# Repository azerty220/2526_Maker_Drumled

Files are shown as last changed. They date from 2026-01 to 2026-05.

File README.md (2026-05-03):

# 2526_Maker_Drumled

## Elise Firmin

### Description :
 
Le projet consiste à mettre des leds sur la caisse-claire d’une batterie. Ces led s’allumeraient lorsque la caisse-claire reçoit un coup. De plus, il y aurait un encodeur permettant de choisir la couleur de l’éclairage.
Le projet a pour but d’être amovible ; c’est-à-dire qu’il puisse être ajouté puis retiré de la caisse claire. 
Une partie conception 3D est envisagée afin de mettre le projet sur le contour de la caisse claire sans gêner les frappes du batteur, et qu’il n’y ait pas besoin de démonter les peaux pour insérer les leds. Ainsi, nous évitons de faire des trous dans une caisse claire afin de relier l’encodeur.

### Quelques images d'une caisse claire et de ce que l'on trouve actuellement sur le marché :

#### Exemple de caisse claire :
Nous pouvons voir le fût sur lequel l'on pourra fixer le système et le déclencheur que l'on ne doit pas gêner en revanche. 

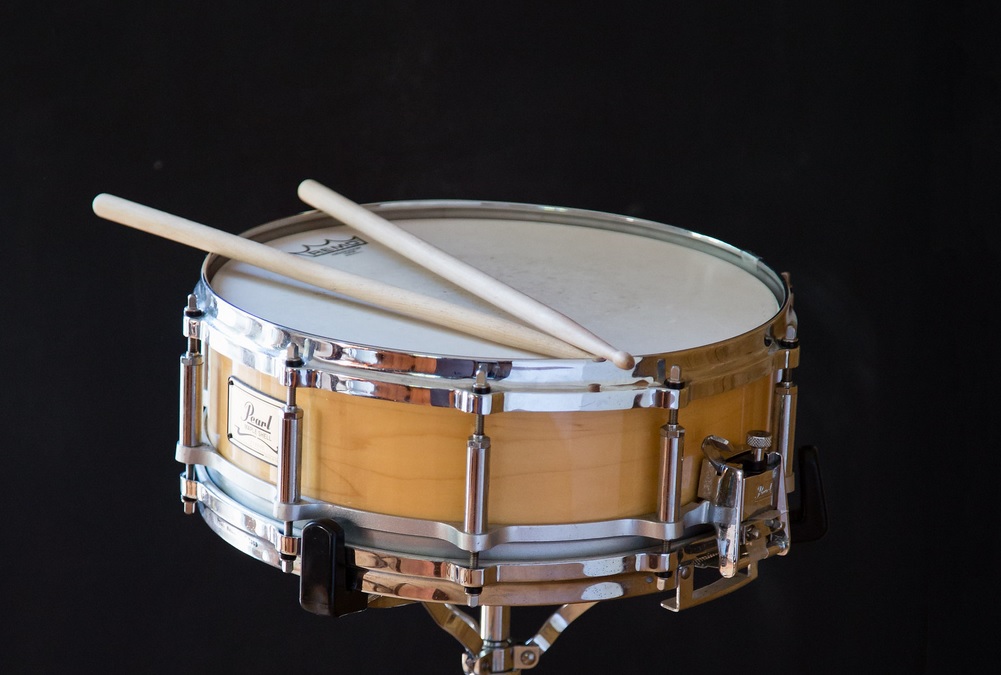
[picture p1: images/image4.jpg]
caisse claire


#### Système d'éclairage existant :

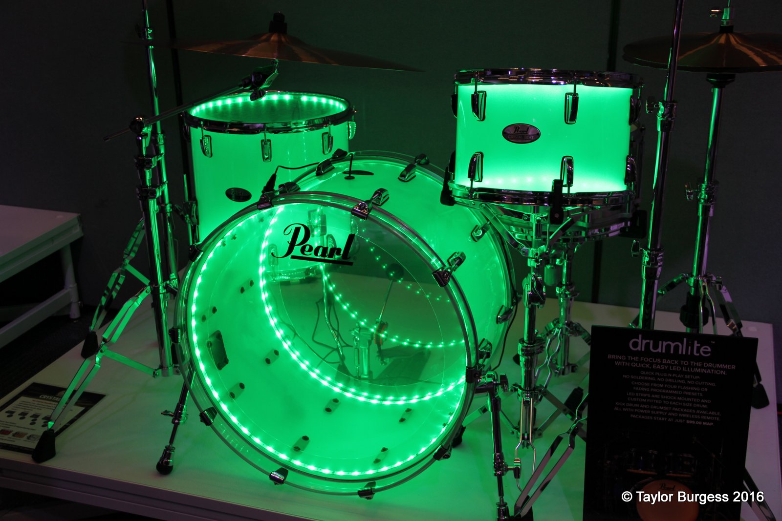
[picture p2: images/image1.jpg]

#####
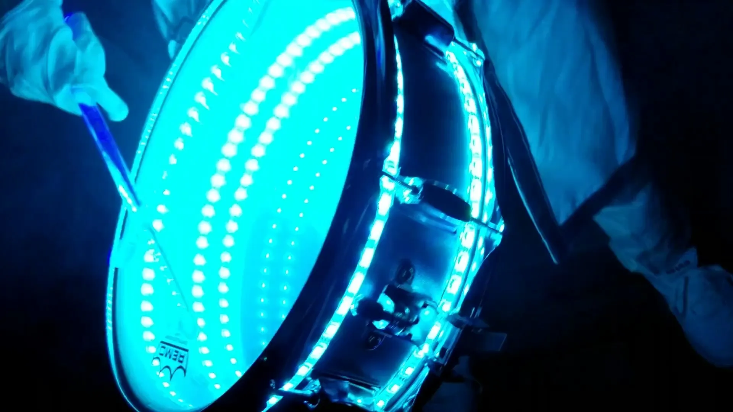
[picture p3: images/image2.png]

#####
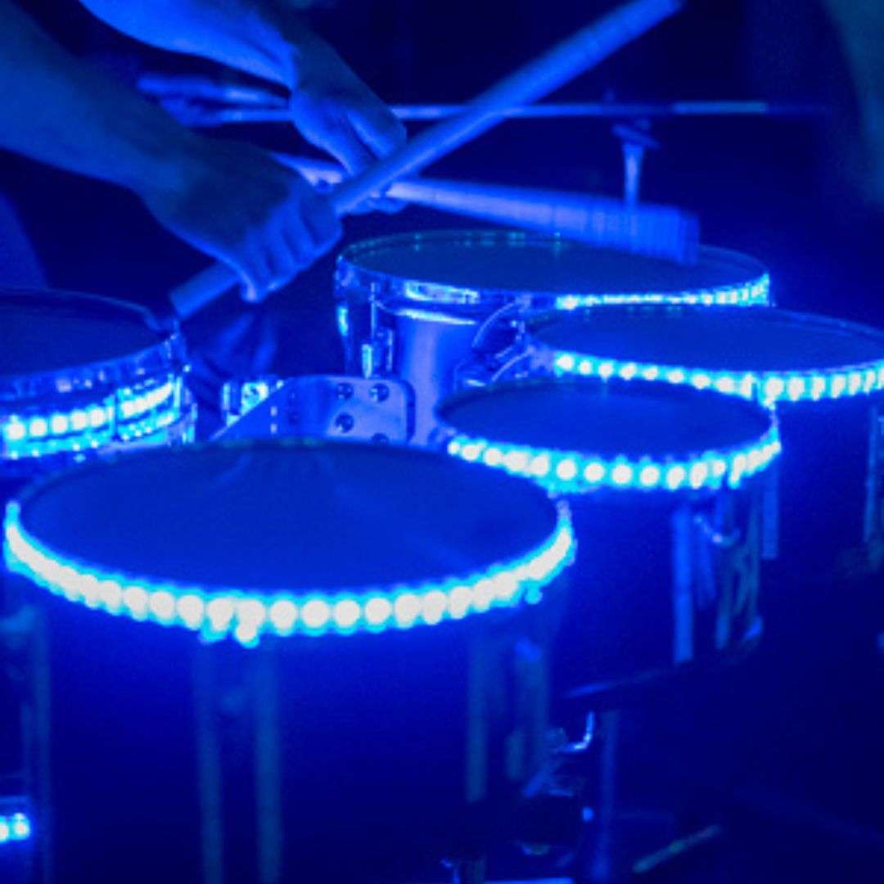
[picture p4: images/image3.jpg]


### Rétroplanning du projet :

Se référer à la partie "Projects" avec le nom "Retroplanning".

retroplanning

## Mécanique :

Il a fallu faire attention que le timbre puisse s'enclencher et se déclencher sans problème. Aussi, ne pas supperposer la partie mécanique aux pièces mécaniques de la caisse-claire elle-même. L'imprimante 3D a été choisie de façon à qu'elle ait un plateau suffisamment grand pour imprimer cette pièce mécanique. 

La partie mécanique se fait en 3 parties :

- 2 parties pour l'anneau autour de la caisse claire, qui s'aimante afin que le tout tienne autour de la caisse-claire. Les aimants sont choisis assez puissants (12kg minimum conseillé), et le tout est assez solide pour ne pas glisser vers le bas. L'une des moitiés d'anneau est adaptée pour recevoir le pcb qui se fixe à l'aide de vis et d'un fer à souder chaud. 

- Le support de la batterie, qui possède 4 trous afin de pouvoir le fixer à l'anneau autour de la caisse claire, à l'aide de vis et d'un fer à soudé chaud.

## Le code :

Le seuil du capteur est à régler dans le code du projet. Le code est séparé en plusieurs parties avec notamment les fonctions importantes qui sont exécutées dans la boucle du main. Un fichier concerne l'acquisition du capteur, un autre les données envoyées à la bande neopixel selon la couleur dirigée par le bouton hardware, et l'acquisition du capteur. 

## La batterie :

Malheureusement, la batterie construite ne permet pas de gérer les appels de courants du circuit, en revanche, en branche une alimentation électrique, le projet est fonctionnel. Il faut changer le composant qui permet de rguler les batteries qui sont en série pour en prendre un plus performant, ou bien utiliser une batterie qui possède une seule cellule est une autre soluton. 

## Le hardware

Plusieurs connectiques de composants ont été adaptées pour avoir des connectiques plus petites et réduire la taille du pcb. Notamment la connectique du ruban de led neopixels pour la convertir en un connecteur jmc de petite taille. 

De plus, lors des tests du projet, le maintien du bouton reset était nécessaire pour la compilatiion du code ; ainsi, la résistance R3 du pcb est inutile : elle s'enlève très facilement du pcb à l'aide d'un coupe-ongle par exemple. Ou bien, sans fer à souder, la température d'un briquet étant de 800°C à 1000°C, cela peut être tenté ; mais attention au risque de brûlure. 

La petite taille du pcb permet un poids léger. 

Le PCB a été conçu à l'aide du logiciel KiCad.

## Piste d'amélioration du projet :

Le projet pourrait être amélioré grâce à des effets codés comme un chazer par exmple, puis un bouton hardware associé. 
De plus, il pourrait être pertinent de mettre un bouton qui permettrait en appuyant 4 fois dessus par l'utilisateur de déterminer un BPM et que les led ne s'allument plus à chaque coup cette fois ci, mais à chaque temps, ce qui constiturait une aide pour le batteur pour conserver le tempo.
En mêlant cette dernière idée avec le projet initial, et étendu à la batterie tout entière, cela donnerait l'accès à des personnes mal entendante à cet instrument, que ce soit une sourdité partiel ou complète.

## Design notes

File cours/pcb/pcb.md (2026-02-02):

UART : communication du Tx vers le Rx. Ligne de 0 et de 1 avec des bits de start, stop. Il faut une masse commune aussi.

I2C : une ligne SDA et SCL pour tous les esclaves. Avec une resistance qui relie les lignes à la masse, dont la valeur est variable selon les cas.

100kHz (standard) : 4.7kohm, 10kohm

400kHz (fast) : 2.2kohm, 4.7kohm

etc

SPI : SCLK, MOSI, MISO, CS (1 par esclave) [CS, CS2, CS3,...]. Plus rapide que l'I2C mais ça nécessite plus de connexion.

USB : pour remplacer l'UART, uniformiser, mais l'UART existe encore parce qu'il est plus facile à mettre en place.

Mettre des résistances de 5k1ohm entre CC1 et la masse et CC2 et la masse.

On met un composant qui a 5 diodes (pour enlever des pics de tension qui surviendrait, s'assurer que la tension soit comprise entre 0 et 5V) : à mettre au plus proche du port usb.

Rajoute du fil sur les pistes les plus courtes pour qu'elles soient de même longueur que les autres pistes.

Mettre une résistance en série (1kohm) puis un condensateur en parallèle vers la masse (0.01microF) et une résistance en parallèle vers du 5V (100k) pour un switch pour éviter les rebonds.

Diode TVS, pour enlever tout ce qui est au dessus d'un certain seuil pour ne pas griller le pcb. A installer au plus proche du connecteur. à chaque connecteur où il y a du signal (connecteur de batterie ce n'est pas intéressant) 

Vdd : transistor haut
Vss : transistor bas

Lorsqu'on crée une empreinte :

alim en haut

masse en bas

Dans le symbol editor 

Symbol Editor > New librairy 

Project > OK, save

SMD ou Through hole (THT) (traversant)

PowerFlag pour corriger, signaler qu'on sait qu'il faut une alim par exemple

Input : Reçoit un signal provenant d’une autre source

Output : Génère un signal destiné à être utilisé par un autre composant. 2 output ne peuvent pas être câblés ensemble

Bidirectionnel : Peut fonctionner à la fois en entrée et en sortie (ex : SDA en I2C)

Power Input : Pin recevant une alimentation (ex : VCC, GND)

Power Output : Pin délivrant une alimentation (ex : sortie d’un régulateur de
tension)

Tri-State : Sortie pouvant être active, inactive ou en haute impédance

Open Collector/Open Drain : Sortie nécessitant une résistance de pull-up pour
fonctionner correctement

Passive : Utilisé pour des connexions simples comme des résistances ou
condensateurs

Unspecified : Type de pin non défini (par défaut dans certains cas)

Point ou triangle sur la pin 1

Faire attention au fait que les dimensions soient en mm, en cm, en pouces,...

F.Cu : Couche de cuivre côté supérieur (composants côté top)

B.Cu : Couche de cuivre côté inférieur (composants côté bottom)

F.Paste : Zone pour la crème à braser sur le top (pour les composants CMS)

B.Paste : Zone pour la crème à braser sur le bottom (pour les composants CMS)

F.Silkscreen : Sérigraphie sur la face supérieure (références, symboles, repères)

B.Silkscreen : Sérigraphie sur la face inférieure

F.Mask : Masque de soudure (protège les pistes, expose les pads pour la soudure)

B.Mask : Masque de soudure sur la face inférieure

F.Courtyard : Délimitation physique de l’empreinte du composant pour éviter les
chevauchements

B.Courtyard : Même chose mais côté Bottom

F.Fab : Informations précises sur la fabrication du PCB, notamment les
dimensions exactes du composant

B.Fab : Même chose mais côté bottom.

F : Front et B : Back

Lorsqu'on est dans une page, et qu'on crée un label hiérarchique (avec petit losance, ou demi carré,... : entrée/sortie d'une "fonction"), il n'apparaît pas automatiquement dans la vue d'ensemble, il faut faire clic droit dans la vue d'ensemble sur la page 

Remplir le MPN (ou MFR) dans tous les composants un peu spécifiques (pas les résistances et condensateurs standards)

Checker le ERC (Electrical Rules Checker) : il ne doit y avoir aucune erreur 

Commencer par définir la taille du pcb, et les trous de fixation

Mettre le microcontrolleur avec beaucoup de pin au milieu

Mettre les connecteurs sur les côtés

Possibilité de switcher deux pins sur la schématique sur un microcontrolleur pour éventuellement faciliter le routage par exemple. 

4 couches : plan de masse et plan d'alimentation

1 via = 1 ampère

JLCPCB : là où on fait fabriquer nos pcb

Pour choisir le nombre de couche et la disposition : deuxième icone à côté de l'icone enregistrer > Physical Stackup (Ne pas changer In1, In2, In3,... pour la fabrication mais la partie "VCC",... on peut)

Option sur jlcpcb : 

1oz = 35 microns

On garde les options de base (1oz ligne 1, 0.5oz ligne 2)

Dimensions inférieuresà100mmx100mm,

4 couches maximum,

Hole size > 0.3mm (extra cost 0.3mm > Hole size > 0.15mm)

Via diameter > 0.45mm (extra cost 0.4mm > Hole size > 0.25mm)

Minimum spacing : 0.09mm -> 0.10mm, 3mil for BGA fan-out

Minimum trace width : 0.16mm

Exercice : 

Se brancher sur la raspberry avec les pogopin avec une sorte de schield à l'arrière, et ressortir le signal sur 4 usb-c

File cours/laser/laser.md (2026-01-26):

### Découpeuse LASER

prédéfini par un fichier vectoriel

#### Types de laser :

- CO2 (ce qu'on a ici)

- Fibre (découpe de métaux)

- Diode (pour de la gravure, ou du papier)

Matériaux compatibles : Bois, contreplaqué, acrylique, cuir, carton, papier, tissu

#### Avantages :
précision élevée, finition nette
#### Précaution :
Ventilation nécessaire pour évacuer les fumées

#### Bois et dérivés :
Contreplaqué, MDF(Medium Density Fiberboard), Bois massif, Liège

#### Plastiques :
Acrylique, Polycarbonate (gravure mais pas découpe)

#### Papiers, cartons :
Carton ondulé, Papier, Carton Plume

#### Tissu et cuir

#### Métaux :
Nous n'avons pas ce qu'il faut, mais on peut le graver

#### à éviter :
PVC (fumées toxiques), maières réfléchissantes (brûler la lentille du laser)

Toujours vérifier la compatibilité du matériaux avec le model du laser

#### Format de fichier :
DXF, DWG, SVG (pas très précis pour des engrenages,... bien pour de la déco), PDF

#### Logiciels :
Inkscape (gratuit), Adobe Illustrator,...

### Découpe laser dans OnShape

Auto Layout : met à plat les pièces

Laser Joint : crée des créneaux entre les pièces

T-Slot Join : créer une extrusion pour l'insertion d'un boulon

 '+' puis créer un dessin puis modèle personnalié puis ISO format A2 par exemple et N'inclue pas et N'inclue pas (pour par qu'il grave le nom du projet, des bordures,...

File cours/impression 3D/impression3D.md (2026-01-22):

### Impression 3D

Le bed : sur quoi repose la pièce 

Nozzle, La buse : par où passe le fil avant d'arriver sur le plateau

Hotend : la tête d'impression, avec la buse

Extruder puis Bowden : tube qui guide le filament jusqu'à la buse

#### Modèles plus récents :

bed : axe z

buse : axe x et y 

extrudeur directement dans la tête (avec la buse)

#### Problèmes qui peuvent subvenir :

décalage de la pièce : l'imprimante imprime dans le vide

la buse se bouche

choc thermique, changement de filament : les couches n'adhèrent pas entre elles

gagner en vitesse d'impression : diminuer la distance de la buse, augmenter la vitesse de la buse.

#### Risques :

Intoxication avec les émanassions 

Brûlures en touchant la buse

Jeu entre deux pièces : 0.3mm minimum pour que ça coulisse

Avec une pièce coudée, avec un angle de 30° s'est le début des bonnes impressions

1.75mm : de base avant de faire changer le diamètre (généralement à 0.4mm) dans la tête

STL : que des segments, donc une courbe : suite de petits segments

*Slicer :* PrusaSlicer, Creality Print (en haut), Bambu Studio (en bas), Orcaslicer

*Printables* : site internet avec des ventes de fichiers d'impression.

Aurélien

#### Filaments ;

*PLA :* matériau classique, T = 195-210° (passer de l'état solide à liquide)

*ABS :* fumées toxiques, et odeurs, mauvaise adhérence au plateau, bien pour des prototypes fonctionnels (contraintes mécaniques, plus robuste)

*PETG :* résistant aux solvants et aux gazs, difficile d'avoir une colle qui fonctionne sur sa surface, robuste avec facilité d'impression

*TPU :* filament flexible, résistant à l'abrasion (milieu avec du sable), contraintes mécaniques, en revanche lent à imprimer

*ASA :* résiste à l'UV et aux intempéries avec température : très bien pour l'extérieur

*Nylon :* très résistant à l'abrasion et à l'usure mais absorbe l'humidité (il faut qu'il sèche). (ex : engrenages, roulements,...)

*PLA/PETG/ASA Chargé :* Carbonne, Verre, Métal : mixé, les mêmes mais déclinés ; peut amener de la légèreté mais donc perdent en robustesse et deviennent abrasives

*PVA* : pour les supports qui sont compliqués à retirer : dans des cavités, support qui se dissout à l'eau chaude (processus en 24h environ) : nécessite deux têtes (différencie PVA des support et impression)

*Composite :* accès métaux et céramique, pour des milieux complexes, basse température et très cassants (machine spécialisées) Usage en RF

Difficile de lier différentes matières entre elles (avec plusieurs buses) donc intéressant pour les supports 

PLA et PETG : matériel que l'on recycle le plus, le Nylon jamais car complexe avec l'humidité 

>> Shore : catégorisation de la flexibilité du matériel 

Shore A et D

PLA (Fablab), ABS, PETG et ASA (atelier mécanique)

Il existe des inserts PLA à mettre avec un fer à souder pour pouvoir avoir de bons filetages, et pouvoir assembler des pièces correctement.

### Réglages

Nombre de murs : à partir de 4 on peut marcher dessus, et ça ne se casse pas

Densité : 15% c'est la norme 

Forme de remplissage : gyroid à la mode : plus grande résistance, mais augmente le temps d'impression 

Garder les speed par défaut

Vitesse lorsque c'est en devers donc il va plus lentement pour que ça refroidisse 

Vitesse de déplacement lorsqu'il n'imprime pas 

Brim : pour rajouter une couche d'adhérence au niveau du plateau en support, si les pièces sont volumineuses et pour bien fixer la pièce

Support : penser à les activer lorsque c'est utile, ce n'est pas par défaut

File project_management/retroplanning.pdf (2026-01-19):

21/02/26 | vacances | 08/03/26
30/01/26 | 06/02/26 | 13/02/26 | 23/02/26 | 26/02/26 | 03/03/26 | 06/03/26 | 13/03/26 | 30/03/26 | 03/04/26 | 13/04/26
1 : Recherches pour le schéma électrique du montage | 2 : Commandes des composants électriques | | 3 : Montage d’un circuit électrique fonctionnel afin de pouvoir faire les codes | 4 : Faire le code avec le bouton ON/OFF permettant d’allumer et éteindre le système | 5 : Faire le code concernant la gestion des données du capteur pour gérer l’intensité des leds | 6 : Faire le code de l’encodeur pour régler le choix de la couleur | 7 : Conception du PCB | 8 : Conception 3D du support du système allant sur la caisse-claire : amovible | 9 : Refonte du circuit led pour l’intégrer à la conception 3D (et relié au PCB) | 10 : Phase de test du projet et préparation à la soutenance

Feuille1

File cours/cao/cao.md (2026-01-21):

## CAO : conception assistée par ordinateur

vector >> courbe

raster >> pixel

Si on veut une belle qualité : utiliser des vecteurs

Résolution de l'imprimante donc on utilise une version raster. 
(Facile de passer de vector à raster)

Logiciel de CAO : SketchUp (pas fait pour être précis), FreeCAD (pas facile d'utilisation), Fusion 360, SolidWorks, Blender (pour des formes non bien définies)
On utilise Onshape

###  On peut exporter les pcb sur onshape.

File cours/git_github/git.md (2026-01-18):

git ==> application 

GitHub ==> serveur pour gérer nos projets ; plateforme pour nos projet git

Git : HadjSassi  

LinkedIn : Mahdi Hadj Sassi  

**git init**

**git config**

**git log** 

**git add .**

**git commit -m"first commit"**   (il faut avoir déjà add avant)

**git status** 

**touch readme.txt** : crée un fichier

**nano readme.txt**

**mkdir nom\_de\_dossier**

**cd nom\_de\_dossier**

git : avoir les anciennes versions

git add puis git commit puis git push 

>> utiliser les virtual machine, avec la possibilité de booster la ram. 

Linux : sudo apt install git 

Windows : https://git-scm.com/install/windows

**git config --global user.name "<username>"**

**git config --global user.email <email>**

dépôt : 2G ou 20 si version payante (5-10€/mois)

certains bot arrivent à accéder aux environnements privés, donc pas de données sensibles. 

readme.md : descriptions, dépendances

.gitignore : ignore certains fichiers du projet Git. Utile pour ne pas synchroniser des fichiers temporaires ou exclure des fichiers tests

les crochets : <xxx /xyx> indique les différenes valeurs possibles 

**ssh-keygen -t <dsa / ecdsa / ecdsa-sk / ed25519 / ed25519-sk> -C"<email>"**

-t : spécifie l'encodage : privilégier ed25519

Windows : cmd ou PowerShell : privilégier PowerShell parce que cmd est plutôt réservé aux administrateurs

PowerShell : autre type de terminal, avec un autre langage (vient en opposition à GitBash) 

cmd et PowerShell n'ont pas les même commandes

Linux : **cat ~/./ssh/<nom-de-votre-clé>.pub** puis copier le retour : copier-coller le contenu de la commande pour récupérer le contenu 

(en opposition au |clip de Windows)

rajouter une clef SSH sur GitHub : Settnigs > SSH and GPG keys > New SSH keys

(Si l'une est compromise)

clone en SSH :

**git@github.com :<user>/<repo>.git**

Ex : git@github.com:azerty220/2526\_Projet2A\_-ampli\_audio-.git

nom de l'utilisateur et du repository

linux : 

**touch readme.md .gitignore** : pour crée les 2 fichiers

changer de branche :

**git branch -M main**

M : branche principale

**git add <fichier1>**

**git add .**

attention en ajoutant tous les fichiers (add .) si jamais on ajoute un fichier que l'on voulait pas avoir en public (fichier environnement), on est obligé de recréer un repository car sinon accès avec les versions passées

quitter l'interface vim : **:q**

**git status** : voir l'état de chaque fichier par rapport aux "zones" Git

**git branch <name>** : crée la branche mais ne change pas de branche

**git switch -c <name>** : crée la branche et permet le changement 

pour passer d'une branche à l'autre : **git switch <name>**

pour supprimer une branche : **git branch -d <name>** : pas conseillé

**git merge <branch>** : à faire sur la branche sur laquelle on veut merge

log : afficher les différents commits

**git log --oneline** : affiche les commits sur une seule ligne

**git log -<n>** : affiche n lignes de log

**git log --graph** : affiche les logs de façon architechturé

**git reset \[--hard] <commit>** : revenir à une version antérieure du projet 

commit : mettre le numéro de la version du commit sur laquelle on veut revenir

**git reset \[--hard] HEAD~<n>** : retour de n commit en arrière 

**Markdown : (idem markdown sur jupyter)**

\# Titre

\## Sous-titre

\### Sous-sous-titre

\*italique\*

\*\*gras\*\*

\*\*\*gras et italique\*\*\*

> citation

-\[x] ou -\[] : checkbox qu'on peut modifier sur GitHub

pour un tableau : on doit mettre le même nombre de tiret que de caractères au dessus :

ici | colonne

----|--------

1 | ya

2 | yi

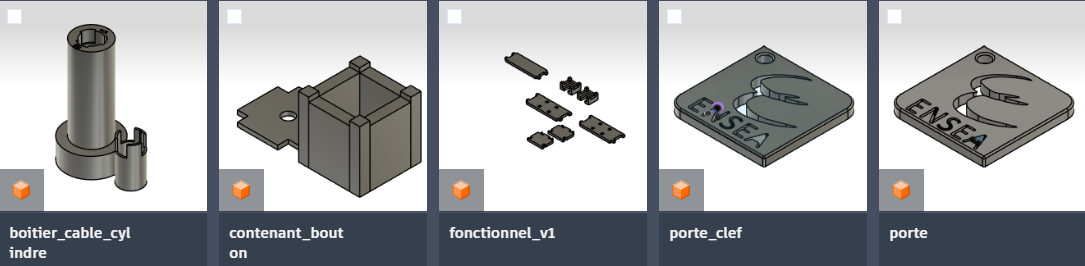
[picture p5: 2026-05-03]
rendus_option_maker_hors_projet/cao/fusion1_5design.png

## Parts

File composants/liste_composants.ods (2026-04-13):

Désignation + Ref | URL | Quantité | P.U. | Prix final | Date de livraison | à commander | en stock
Led THT RGB + HV-5RGB60 | https://www.mouser.fr/ProductDetail/Inolux/HV-5RGB60?qs=qSfuJ%252Bfl%2Fd7yi2o6d75%2FlQ%3D%3D | 40 | 0,64 € | 25,56 € | 1 mois
Encoder |  | 1 | // | // | //
Capteur accéléromètre |  | 1 | // | // | //
Microcontôlleur – STM32G431KBT6 |  | 1 | // | // | //
Pile ? / Batterie
Switch ON/OFF
Boîtier pile
Nanopixel
MISE A JOUR :
 | Quantité
Led NeoPixel | 1
Capteur accéléromètre | 1
Microcontôlleur – STM32G431KBT6 | 1
Bouton | 2
Switch ON/OFF | 1
Batterie (fait maison) | 1
Régulateur | 1
Connecteur Stlink | 1

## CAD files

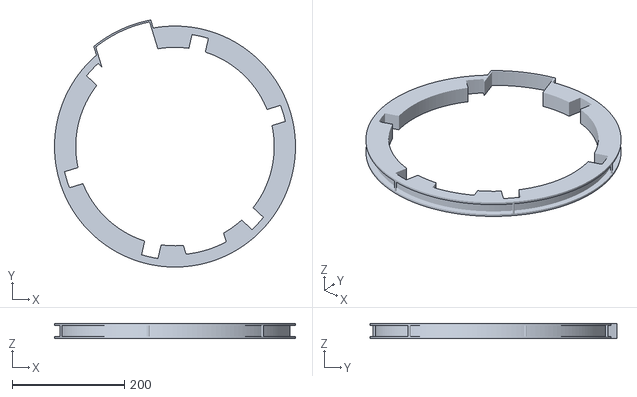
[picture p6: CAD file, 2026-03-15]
conception_3d/drumled_sans_pcb_sans_accroche.stl
430.0 x 440.9 x 27.0

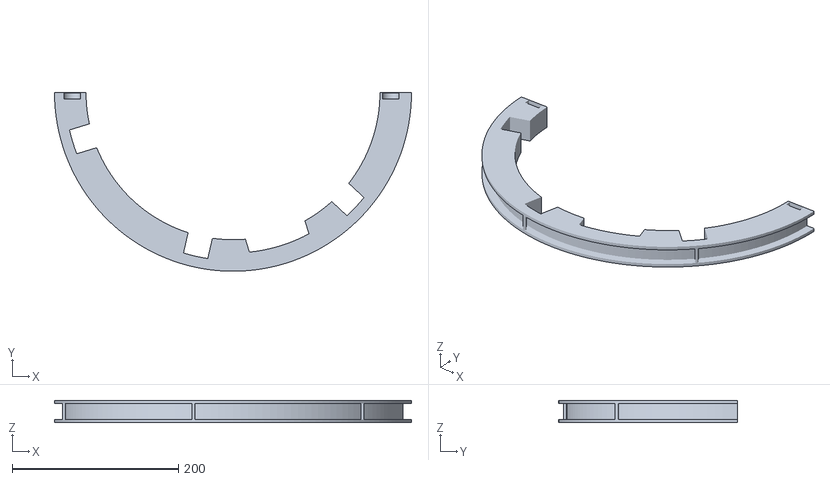
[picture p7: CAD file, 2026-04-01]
conception_3d/pieces_finales/anneau_1.stl
430.0 x 215.0 x 27.0

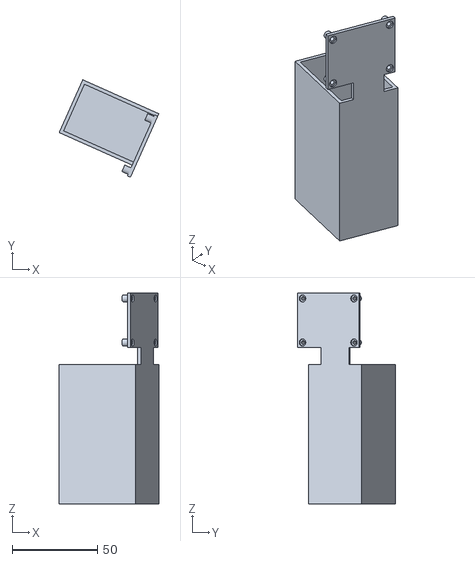
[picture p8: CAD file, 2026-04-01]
conception_3d/pieces_finales/contenant_batterie.stl
58.6 x 57.3 x 124.0

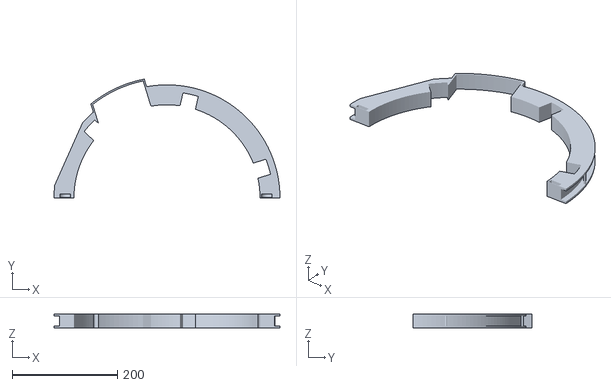
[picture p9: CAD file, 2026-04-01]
conception_3d/pieces_finales/anneau_2.stl
430.0 x 225.9 x 27.0

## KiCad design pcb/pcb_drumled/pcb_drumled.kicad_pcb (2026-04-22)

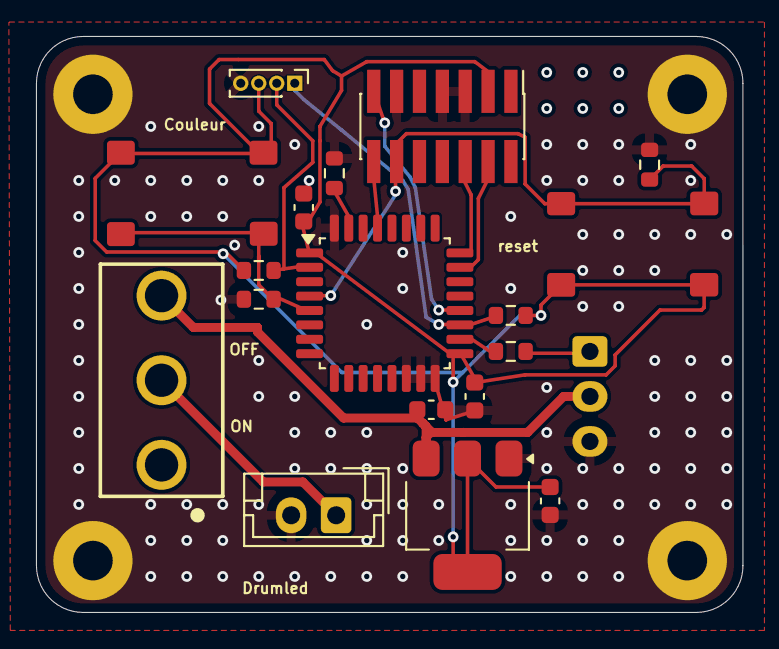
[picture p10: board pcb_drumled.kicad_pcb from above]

Board: 2 copper layers, 39.3 x 32.0 mm, 23 parts (0 on the bottom side), 15 nets.

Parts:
C1: 10u; C_0603_1608Metric
C2, C3: 100n; C_0603_1608Metric
C4: 100u; C_0603_1608Metric
H1, H2, H3, H5: MountingHole_Pad; MountingHole_2.2mm_M2_Pad
J2: Conn_ST_STDC14; PinHeader_2x07_P1.27mm_Vertical_SMD
R1, R2: 4k7; R_0603_1608Metric
R3, R4, R5: 10k; R_0603_1608Metric
R7: 300; R_0603_1608Metric
U1: STM32G431KBTx; LQFP-32_7x7mm_P0.8mm
bouton_couleur1: SW_Push; button
connecteur_batterie1: Conn_01x02_Pin; JST_EH_B2B-EH-A_1x02_P2.50mm_Vertical
connecteur_capteur1: Conn_01x04_Pin; PinHeader_1x04_P1.00mm_Vertical
regulateur_vers_3.3V1: LD1117S33TR_SOT223; SOT-223-3_TabPin2
reset1: SW_Push; button
rgb_neopix1: Conn_01x03_Pin; JST_EH_S3B-EH_1x03_P2.50mm_Horizontal
switch_on_off1: 472123020311

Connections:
3.3V: C2.1, C3.2, C4.2, J2.3 (VCC), R1.2, R2.2, U1.1 (VDD), U1.17 (VDD), bouton_couleur1.2, connecteur_capteur1.3, regulateur_vers_3.3V1.2 (VO), reset1.2
5V: C1.2, regulateur_vers_3.3V1.3 (VI), rgb_neopix1.2, switch_on_off1.3 (A)
DATA_IN: R7.2, rgb_neopix1.1
GND: C1.1, C2.2, C3.1, C4.1, H1.1, H2.1, H3.1, H5.1, J2.5 (GND), J2.7 (GND), J2.11 (GNDDetect), R3.2, R4.2, R5.2, U1.14 (VSSA), U1.15 (VDDA), U1.16 (VSS), U1.32 (VSS), connecteur_batterie1.2, connecteur_capteur1.4, regulateur_vers_3.3V1.1 (GND), rgb_neopix1.3
unnamed: R7.1, U1.18 (PA8)
unnamed: R5.1, U1.31 (PB8)
PA0: R4.1, U1.5 (PA0), bouton_couleur1.1
RESET: J2.12 (~RST), R3.1, U1.4 (PG10), reset1.1
RX: J2.13 (VCP_RX), U1.20 (PA10)
SCL: R1.1, U1.19 (PA9), connecteur_capteur1.1
SDA: R2.1, U1.2 (PF0), connecteur_capteur1.2
Switch2: connecteur_batterie1.1, switch_on_off1.2 (B)
TX: J2.14 (VCP_TX), U1.29 (PB6)
T_SWCLK: J2.6 (JCLK/SWCLK), U1.24 (PA14)
T_SWDIO: J2.4 (JTMS/SWDIO), U1.23 (PA13)

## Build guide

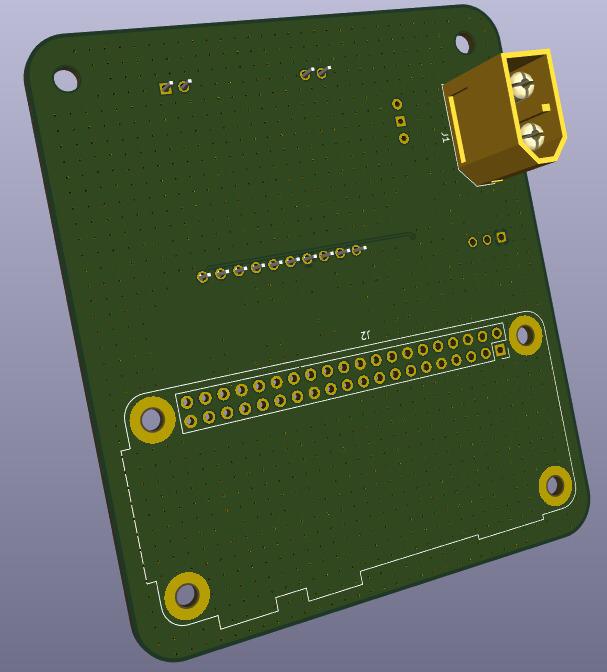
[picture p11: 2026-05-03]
rendus_option_maker_hors_projet/pcb/pcb hackathon/visuel2.jpeg

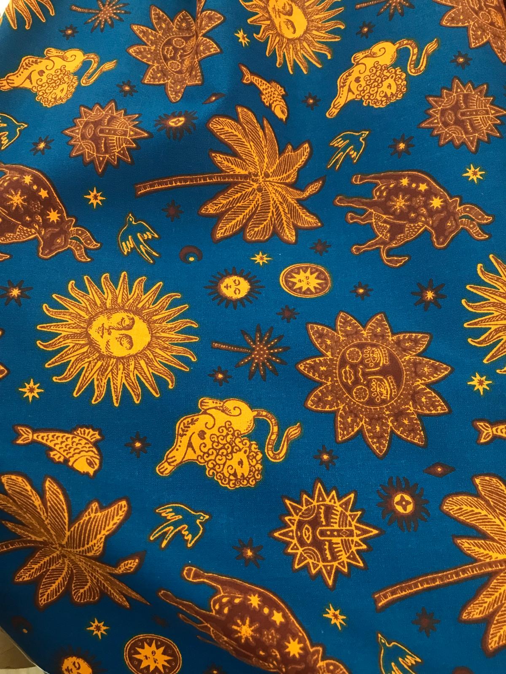
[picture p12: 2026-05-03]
rendus_option_maker_hors_projet/couture/tissu_marche_st_pierre2.jpeg

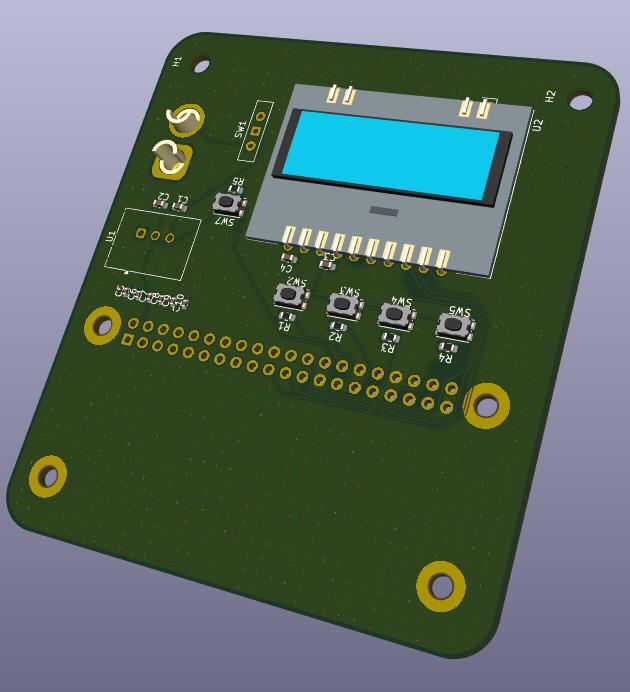
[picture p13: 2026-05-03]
rendus_option_maker_hors_projet/pcb/pcb hackathon/visuel.jpeg

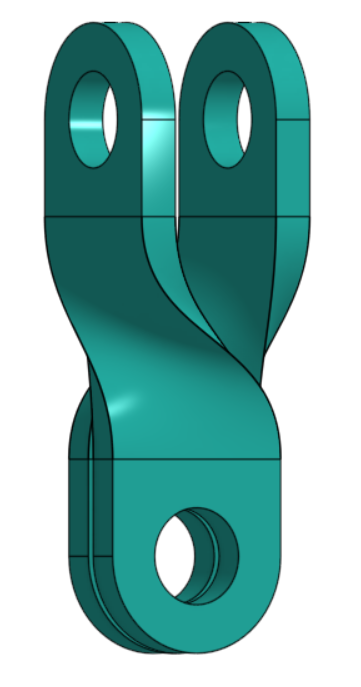
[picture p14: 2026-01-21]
rendus_option_maker_hors_projet/cao/exercice4.png

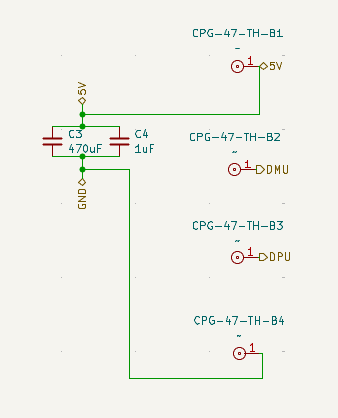
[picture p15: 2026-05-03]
rendus_option_maker_hors_projet/pcb/pcb/schematique3.png

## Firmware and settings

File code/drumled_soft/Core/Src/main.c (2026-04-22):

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
/* Includes ------------------------------------------------------------------*/
#include "main.h"
#include "i2c.h"
#include "tim.h"
#include "usart.h"
#include "gpio.h"

/* USER CODE BEGIN Includes */
#include "lsm6dsox.h"
#include <stdio.h>
#include "light.h"
/* USER CODE END Includes */


void SystemClock_Config(void);
/**
  * @brief  The application entry point.
  * @retval int
  */
int main(void)
{

  /* MCU Configuration--------------------------------------------------------*/

  /* Reset of all peripherals, Initializes the Flash interface and the Systick. */
  HAL_Init();

  /* Configure the system clock */
  SystemClock_Config();

  /* Initialize all configured peripherals */
  MX_GPIO_Init();
  MX_I2C2_Init();
  MX_USART1_UART_Init();
  MX_TIM1_Init();
  /* USER CODE BEGIN 2 */
  LSM6DSOX_Init(&hi2c2);
  AccelData_t accel;
  /* USER CODE END 2 */

  /* Infinite loop */
  /* USER CODE BEGIN WHILE */
  while (1)
  {
	  handle_button();
	  changement_couleur();

	  LSM6DSOX_ReadAccel(&hi2c2, &accel);
	  if (LSM6DSOX_DetectShock(&accel)){
		  printf("j'ai dépassé le seuil\r\n");
		  neopixel_set_color(red, green, blue);
	  }
	  else{
		  printf("toujours pas\r\n");
		  neopixel_set_color(0,0,0);
	  }
	  HAL_Delay(10);
    /* USER CODE END WHILE */

    /* USER CODE BEGIN 3 */
  }
  /* USER CODE END 3 */
}

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


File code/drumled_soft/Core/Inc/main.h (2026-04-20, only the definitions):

#define sda_capteur_Pin GPIO_PIN_0
#define sda_capteur_GPIO_Port GPIOF
#define bouton_couleur_Pin GPIO_PIN_0
#define bouton_couleur_GPIO_Port GPIOA
#define tim_neo_Pin GPIO_PIN_8
#define tim_neo_GPIO_Port GPIOA
#define scl_capteur_Pin GPIO_PIN_9
#define scl_capteur_GPIO_Port GPIOA
#define rx_test_Pin GPIO_PIN_10
#define rx_test_GPIO_Port GPIOA
#define tx_test_Pin GPIO_PIN_6
#define tx_test_GPIO_Port GPIOB

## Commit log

2026-04-03 je sais plus
    [pcb_drumled.kicad_pcb]
2026-05-03 Expand README with project details and improvements
    Added detailed sections on mechanics, code, battery, hardware, and potential improvements for the project.

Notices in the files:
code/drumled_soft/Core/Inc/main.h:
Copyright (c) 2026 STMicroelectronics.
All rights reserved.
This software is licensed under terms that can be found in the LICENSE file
